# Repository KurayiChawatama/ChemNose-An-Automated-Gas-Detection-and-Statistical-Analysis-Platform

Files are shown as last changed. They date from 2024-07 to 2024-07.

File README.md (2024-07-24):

# ChemNose:An Automated Gas Detection and Statistical Analysis Platform

<div style="text-align: center;">
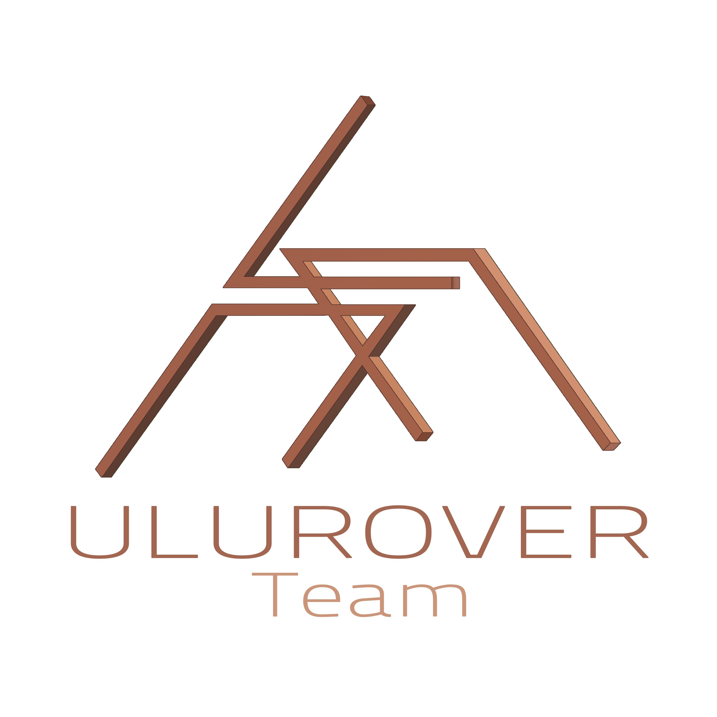
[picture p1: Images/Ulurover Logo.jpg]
ULUROVER Logo ULUROVER LOGO
    
</div>

## Table of Contents
- [Overview](#overview)
- [Materials And Methods](#materials-and-methods)
  - [The Weather Station Module](#the-weather-station-module)
    - [The Weather Station Module Carrying Case](#the-weather-station-module-carrying-case)
  - [The Gas Measurement Chamber For The Gas Detection Modules](#the-gas-measurement-chamber-for-the-gas-detection-modules)
  - [The Soil Moisture Module](#the-soil-moisture-module)
- [Data Analysis Pipeline](#data-analysis-pipeline)
  - [Weather Station Data Analysis](#weather-station-data-analysis)
  - [Gas Detection Data Analysis](#gas-detection-data-analysis)
  - [Soil Moisture Data Analysis](#soil-moisture-data-analysis)
- [Future Directions For the Project](#future-directions-for-the-project)

## Overview
ChemNose is an arduino based gas detection and chemical reaction observation platform. It is designed to be a low cost, portable, and easy to use platform for detecting gases and observing chemical reactions. The platform is built around an Arduino Uno and uses a variety of sensors to detect gases and observe chemical reactions. The platform is designed to be modular and expandable, allowing users to add additional sensors and modules as needed.

It was primarily designed for and used in simulated Mars and Moon exploration science missions for the Anatolian Rover Challenge 2024 by Uludağ University Rover Team (ULUROVER).
Their science team, under my leadership had a hypothesis investigating the habitability of Mars and Moon for Methanogenic Microorganisms. With this in mind, I designed the platform and data analysis pipeline to fit this task.

## Materials And Methods

The platform was built to mainly investigate the habitability of Mars for Methanogenic Microorganisms alongside other chemical assays that are beyond the scope of this document. The main simplified assumption of how a methanogenic microorganisms produce methane is outlined in the diagram below:

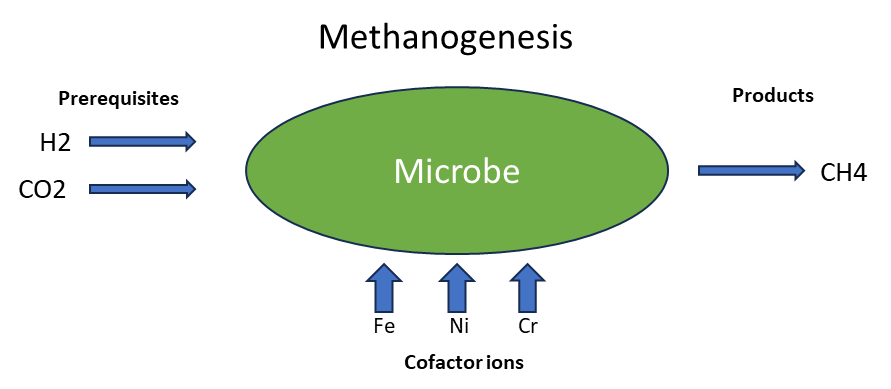
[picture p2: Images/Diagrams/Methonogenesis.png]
Methanogenesis Process Methanogenesis Diagram


The presence of and changes in the concentrations in ppm of the gases CO2, CH4 and H2 were measured using the MQ-135, MQ-4 and MQ-8 gas sensors respectively. The test for the presence of the other ions necessary for cofactors was done using ion specific chemicals assays.  

The general form of the platform 's pipeline is shown in the diagram below:

Pipeline Diagram Platform Pipeline Diagram

The platform consists of 4 modules:
- The Weather Station Module
- The Gas Detection Module with no SD card functionality
- The Gas Detection Module with SD card functionality
- The Soil Moisture Module

### The Weather Station Module

This is the main module that was designed to be run independent of a direct computer connection of the arduino uno. It's main purpose is to measure the temperature, humidity, CH4, CO2 and H2 concentration in the air during the Rover's missions. The data is stored in a SD card for later analysis as a timestamped CSV file in the %m/%d/%Y %H:%M:%S format. Readings are taken every 2 seconds to reduce error of the sensors for the output of a high quality dataset. 
The circuit diagram for the weather station module is shown below:

Weather Station Circuit Diagram

It consists fo the following sensors:
- DHT11 Temperature and Humidity Sensor
- MQ-135 Gas Sensor
- MQ-4 Gas Sensor
- MQ-8 Gas Sensor
- DS3231 RTC Module
- SD Card Module

**The components are configured as follows:**

DHT11 connections:
- D2

RTC connections:
- RST- D8
- DAT - D6
- CLK- D7
- **Note** RTC uses 3.3V not 5V

SD connections:
- CS- D4
- SCK- D13
- MOSI- D11
- MISO- D12

MQ-135: A0
MQ-4: A3
MQ-8: A1

#### The Weather Station Module Carrying Case

A 3D printable carrying case for the module was designed for easy mounting on the rover. It is a modular 3 piece design that can be easily assembled and disassembled. The design files for the carrying case can be found in the [`Weatherbox 3D Printable`](Weatherbox 3D Printable) folder.The overall schematics for the carrying case is shown below:

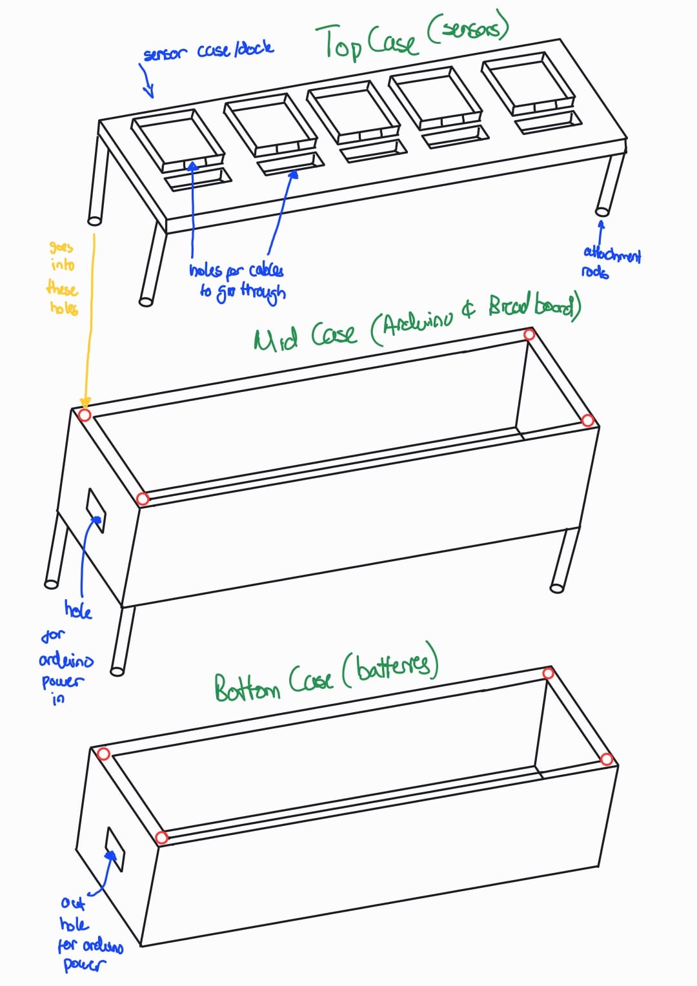
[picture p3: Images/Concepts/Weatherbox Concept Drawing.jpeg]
Weather Station Case Schematics


Placement of the circuit components in the case is shown below:

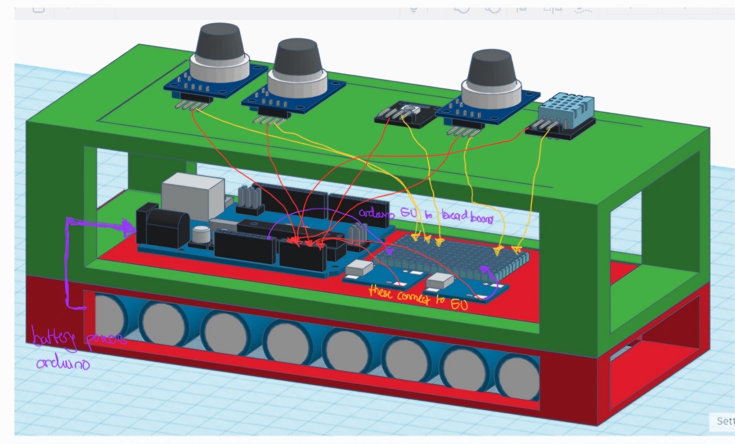
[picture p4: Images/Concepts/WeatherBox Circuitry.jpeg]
Weather Box Circuitry Placement


_(note, batteries are to be placed in two 4 AA battery holders that go into the bottom section of the case not side by side as the diagram depicts)_

The sensors will sit int the designated slots in the top of the case similar to the image shown below:

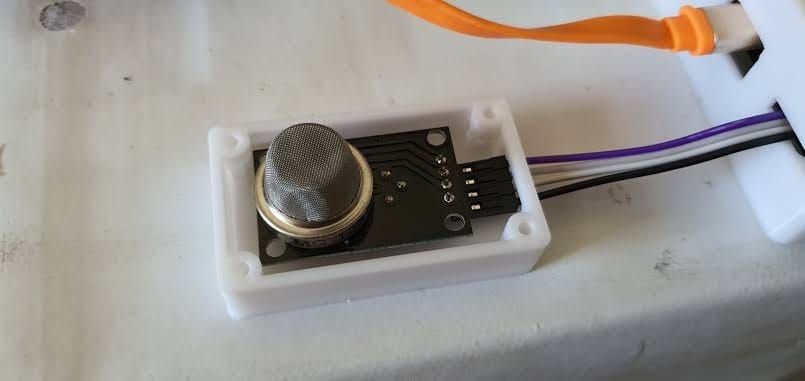
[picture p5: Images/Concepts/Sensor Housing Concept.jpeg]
Weather Box Sensor Placement


### The Gas Measurement Chamber For The Gas Detection Modules

The Circuit Diagram for the Gas Detection Modules are shown below:

<div style="display: flex; align-items: flex-start;">
    <div style="margin-right: 20px;">
        Gas Detection Circuit Diagram
        <p style="text-align: left;"><em>(without SD card functionality)</em></p>
    </div>
    <div>
        Gas Detection Circuit Diagram with SD Card Functionality
        <p style="text-align: left;"><em>(with SD card functionality)</em></p>
    </div>
</div>

It consists fo the following sensors:
- DHT11 Temperature and Humidity Sensor
- MQ-135 Gas Sensor
- MQ-4 Gas Sensor
- MQ-8 Gas Sensor
- SD Card Module(Optional)

**The components are configured as follows:**
SD connections:
- CS- D4
- SCK- D13
- MOSI- D11
- MISO- D12

MQ-135: A0
MQ-4: A3
MQ-8: A1

A novel 350ml closed gas chamber was designed and made using an airtight plastic container with holes to tightly fit the gas sensors. This allows for greater accuracy of the gs measurements. The chamber is setup is shown below:

<div style="display: flex; justify-content: space-around; align-items: center;">
    <div>
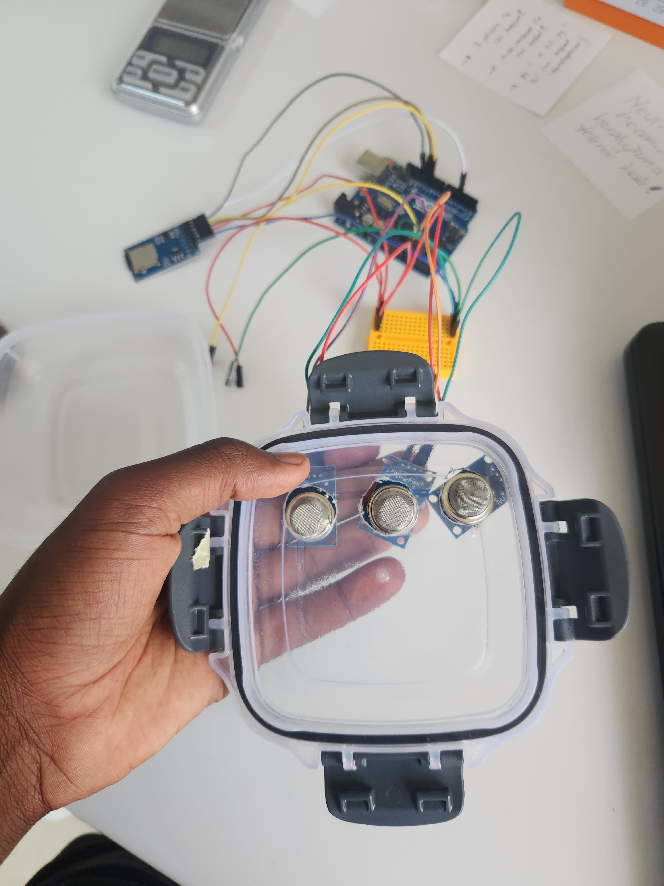
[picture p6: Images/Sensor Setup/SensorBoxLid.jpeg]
Sensor Box Lid
        
        <p style="text-align: center;"><em>Sensor Box Lid</em></p>
    </div>
    <div>
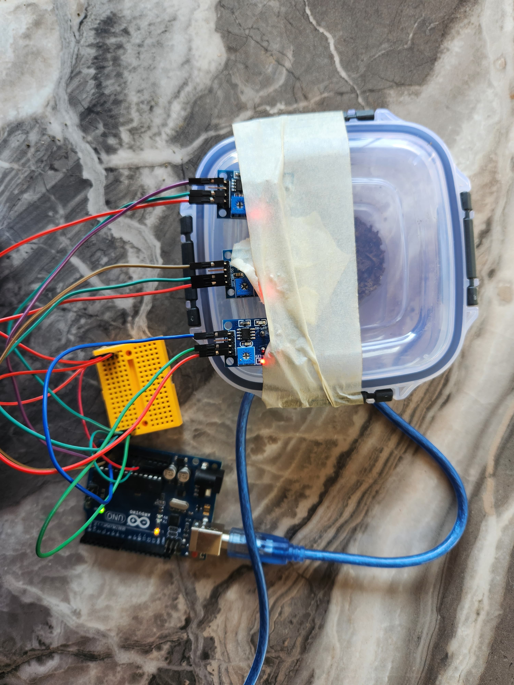
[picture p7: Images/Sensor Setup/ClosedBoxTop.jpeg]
Closed Box Top View
        
        <p style="text-align: center;"><em>Closed Box Top View</em></p>
    </div>
    <div>
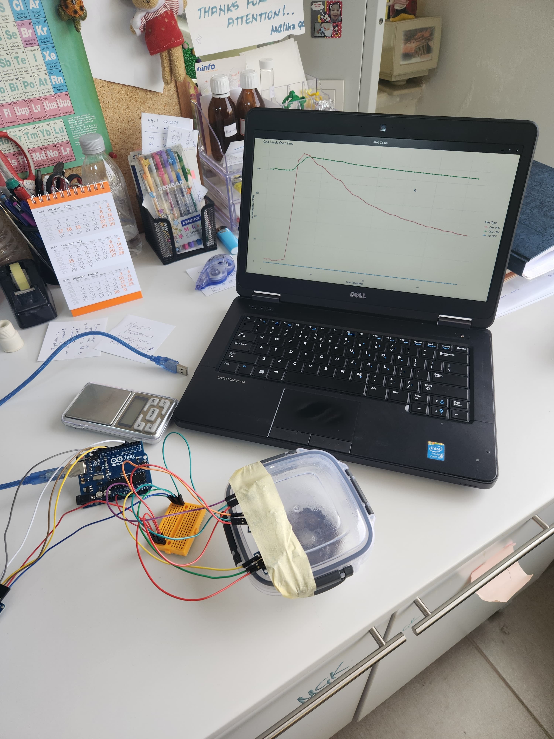
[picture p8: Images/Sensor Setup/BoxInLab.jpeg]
Box in Laboratory Setting
        
        <p style="text-align: center;"><em>Box in Laboratory Setting</em></p>
    </div>
    <div>
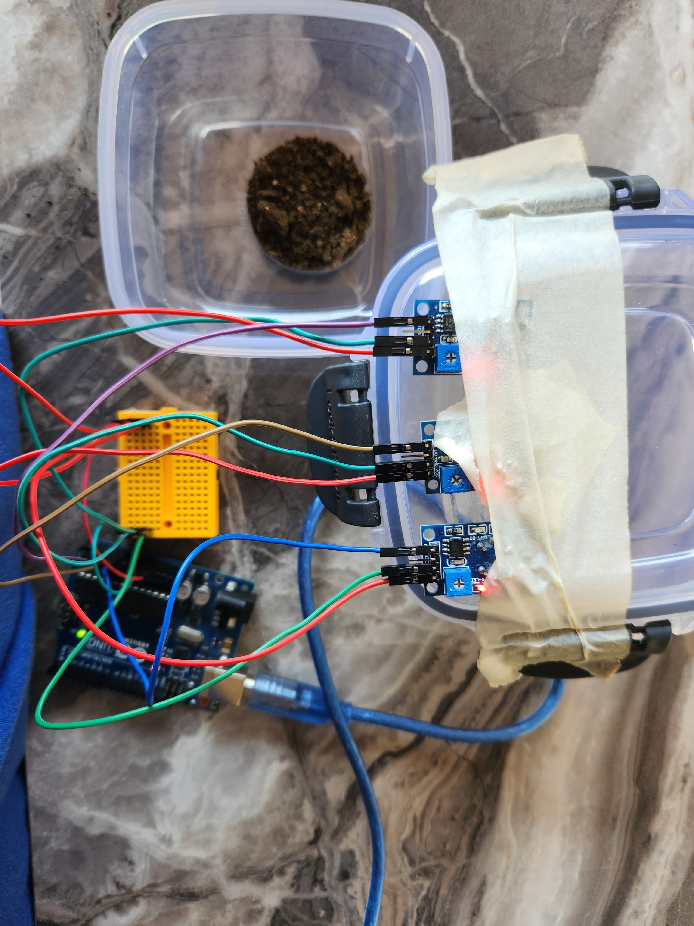
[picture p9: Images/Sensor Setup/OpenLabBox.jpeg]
Open Box in Laboratory
        
        <p style="text-align: center;"><em>Open Box in Laboratory</em></p>
    </div>
</div>

### The Soil Moisture Module

For measurement and classification of soil sample humidity in the lab setting, another module was designed using an arduino uno and a soil moisture sensor. **_This setup requires no specialized housing and does not return a CSV output for analysis_**. The circuit diagram for the soil moisture module is shown below: 

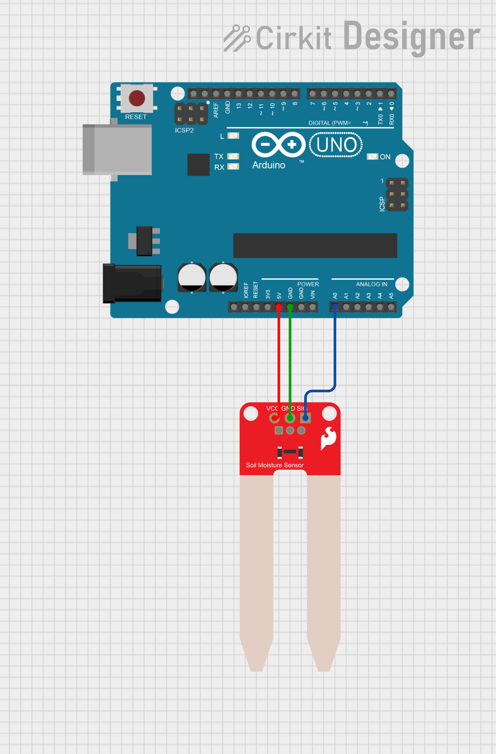
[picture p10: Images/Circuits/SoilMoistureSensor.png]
Weather Station Circuit Diagram


## Data Analysis Pipeline

### Weather Station Data Analysis

**Step 1: Data Collection**  
Set up the Weather Station Module and run the [Arduino_code/weatherStationNoUv/weatherStationNoUv.ino](Arduino_code/weatherStationNoUv/weatherStationNoUv.ino) Arduino sketch on the Arduino Uno. The data will be stored in a CSV file on the SD card in a name of your choosing.

**Step 2: Data Analysis**  
Retrieve the CSV file from the SD card and move it into the repository folder called [Sensor_data](Sensor_data). The data titled `DAY1.csv` and `DAY2.csv` is an example of the data that will be collected.  
Boxplot alongside textual summary statistics and Line plots of the metrics can be obtained by using the [R_code/day2Boxes.R](R_code/day2Boxes.R) and [R_code/day2Lines.R](R_code/day2Lines.R) scripts.

They generate plots like the ones shown below:

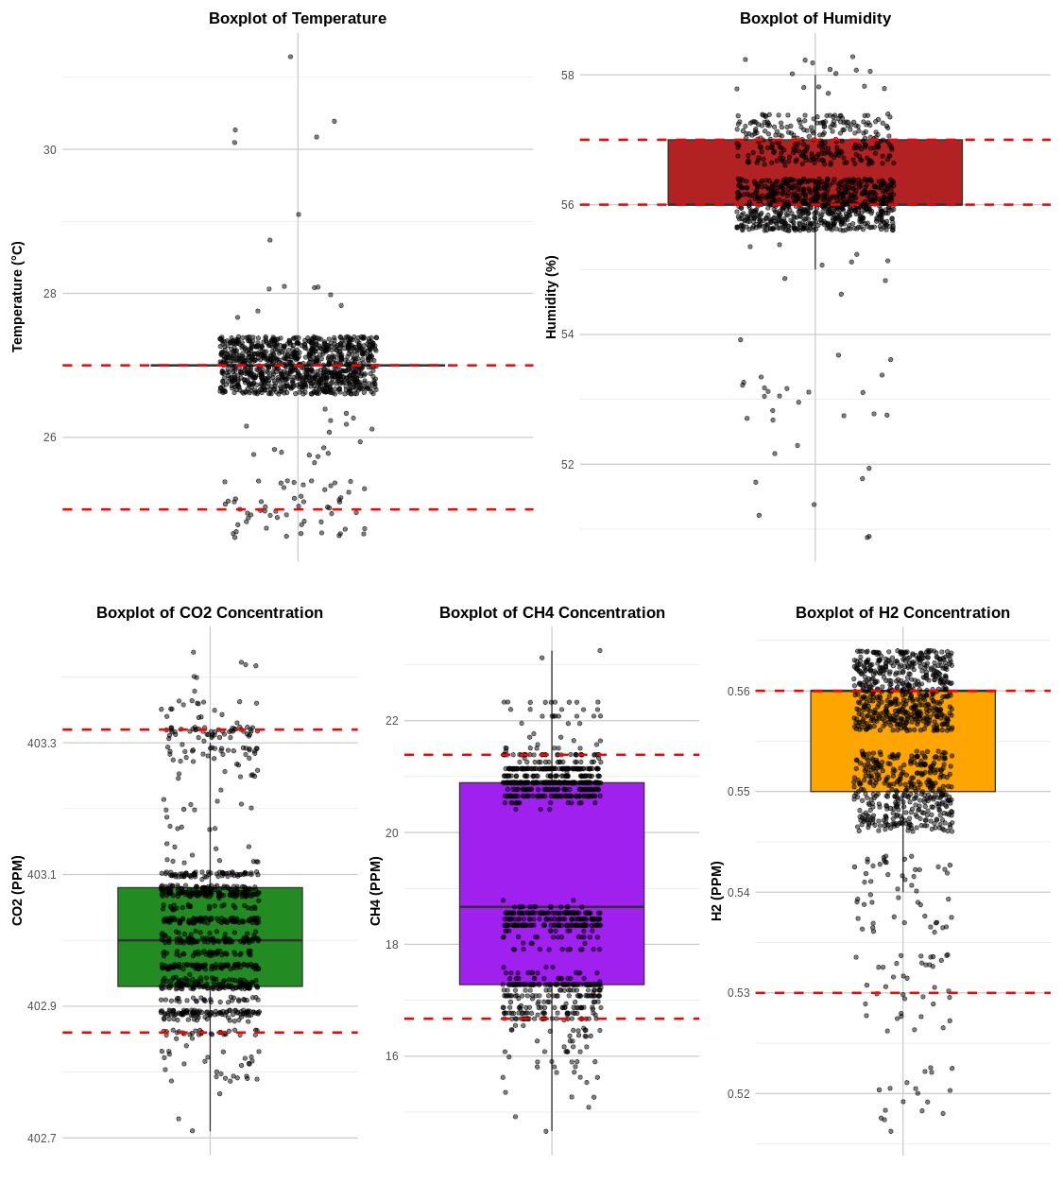
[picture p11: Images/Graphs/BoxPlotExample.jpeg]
Box Plot Example


_Box Plot Example_

Line Plot For Weather Example

_Day Line Plot Example_

### Gas Detection Data Analysis
The data analysis for gas can be done one of two ways; A mode purely for observation of gas levels in a soil sample or given reaction in the gas chamber and the second being a mode where data from multiple soil samples is compared together. 

Step 1: Data Collection
Set up the Gas Detection Module and run the [Arduino_code/MQsWSDCard/MQsWSDCard.ino](Arduino_code/MQsWSDCard/MQsWSDCard.ino) Arduino sketch on the Arduino Uno. The data will be stored in a CSV file on the SD card in a name of your choosing, or alternatively you can copy and paste the CSV output from the serial monitor and into a new CSV file.

Step 2: Data Analysis
- To simply observe the changes in gas levels in a soil sample or given reaction over time, you can use the [R_code/peroxideTestLine.R](R_code/peroxideTestLine.R) script. This script generates a line plot of the gas levels over time. To test the script, you can use the soilGasSample data or the Peroxide Reaction data in the [Sensor_data](Sensor_data) folder. This produces a plot like the one shown below:

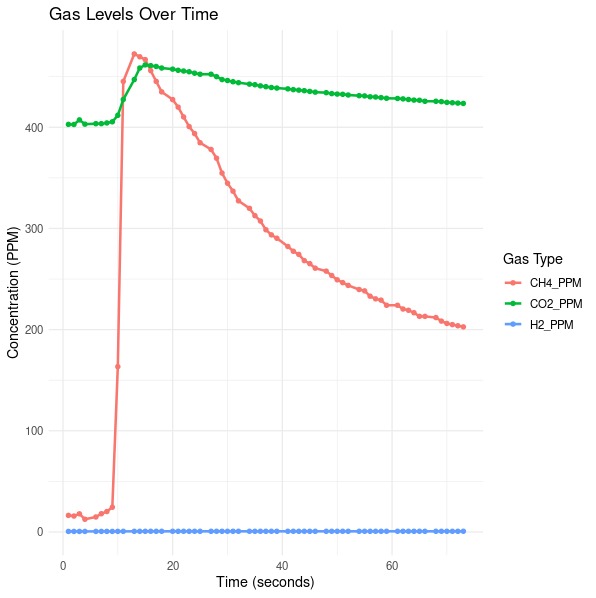
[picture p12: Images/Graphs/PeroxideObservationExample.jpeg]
Soil Gas Sample Line Plot


_Gas Change Over Time Line Plot. When Observing reactions sharper peaks indicate more vigorous reactions_

- To compare the changes in gas levels in multiple soil samples as well as an empty chamber, you can use the [R_code/barAllSoilComparison.R](R_code/barAllSoilComparison.R) and the [R_code/lineAllSoilComparison.R](R_code/lineAllSoilComparison.R) script. These scripts generate a patched graphic of line plots of gas change over time and bar plots of mean changes per gas side by side respectively. To test the script, you can use the soilGasSample data in the [Sensor_data](Sensor_data) folder. This produces plots like the ones shown below:

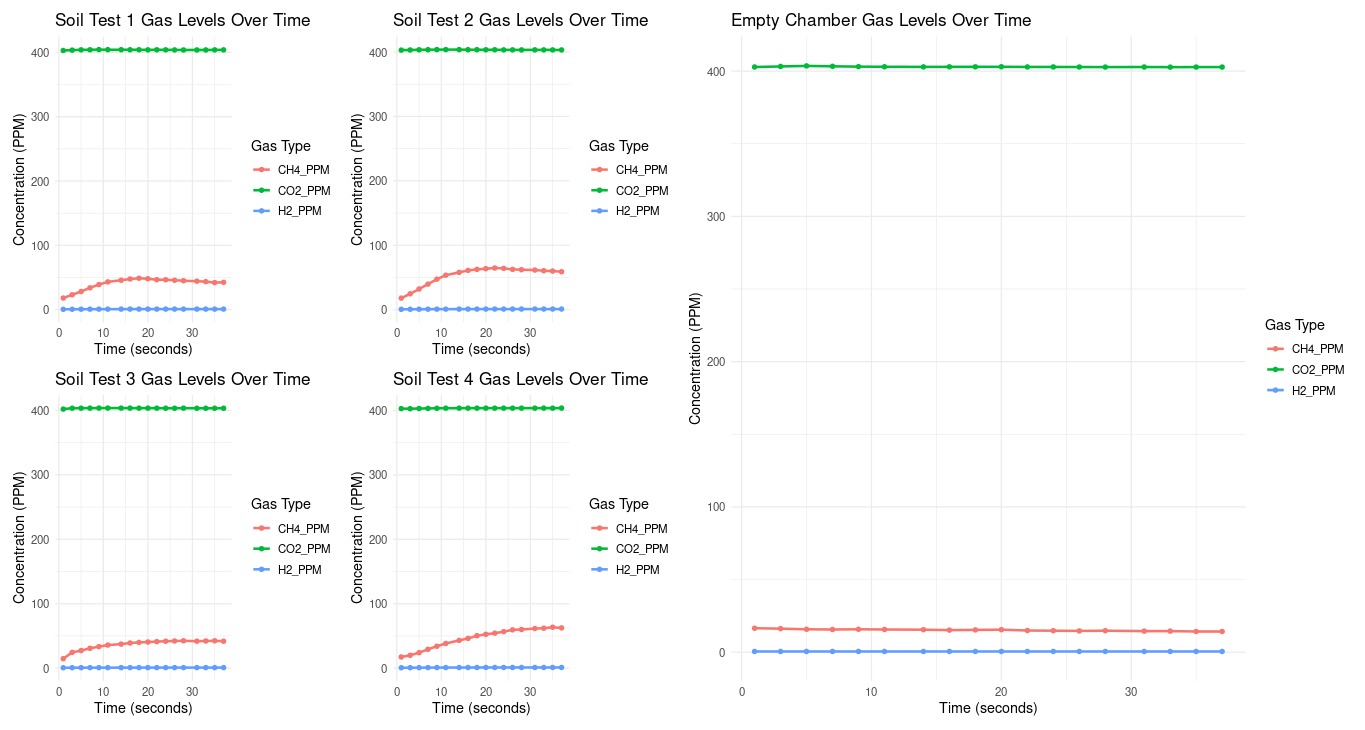
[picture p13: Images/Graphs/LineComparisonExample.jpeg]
All Soil Line Plot


_Multiple Sample Gas Change Over Time Comparison Line Plot_

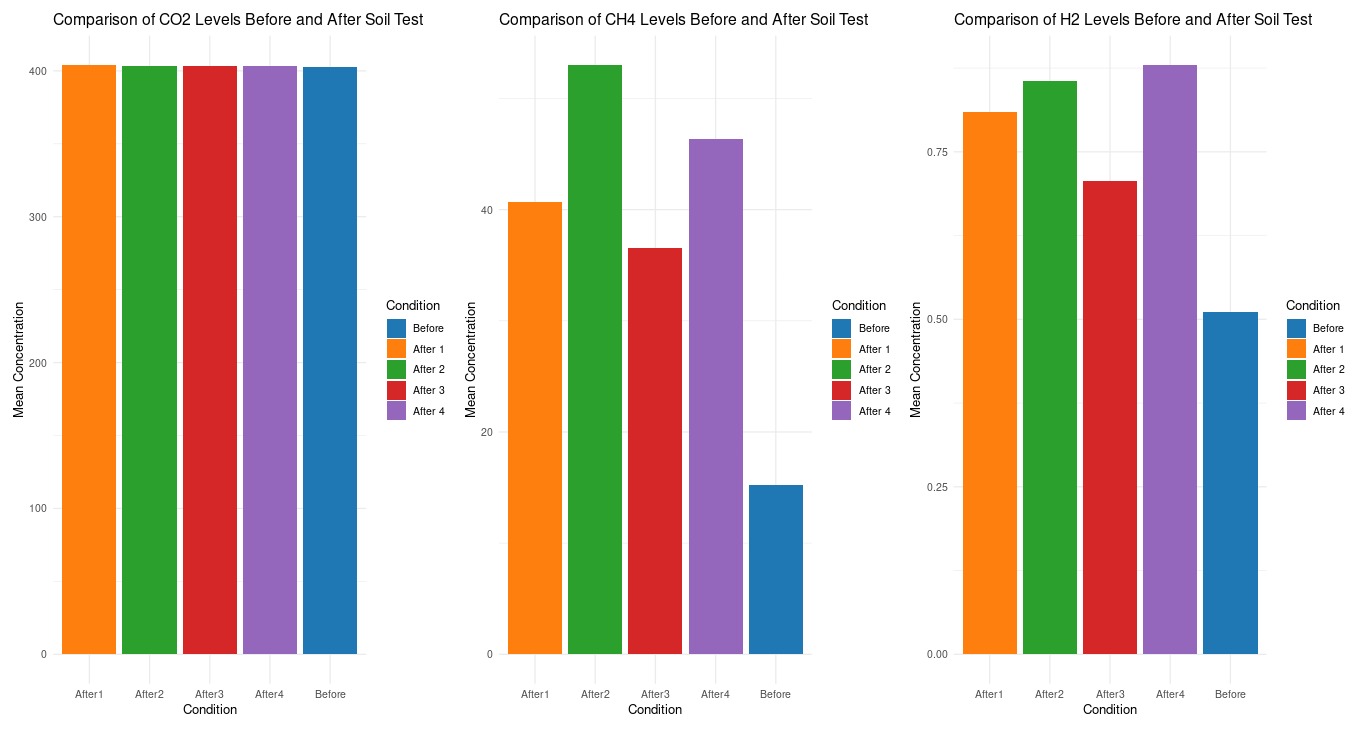
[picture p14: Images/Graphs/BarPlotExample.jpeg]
All Soil Bar Plot


_Multiple Sample Means Comparison Bar Plot_

- The [R_code/WilcoxonSigned-RankTest.R](R_code/WilcoxonSigned-RankTest.R) script can be used to perform a Wilcoxon Signed Rank Test on the data to determine if there is a significant difference in the gas levels between the soil samples and an empty gas chamber such that a conclusion can be made that the soil is the source of the gas. This script generates a textual output of the test results. To test the script, you can use the soilGasSample data in the [Sensor_data](Sensor_data) folder. The test follows the hypotheses:

```
(H₀): μ CH4 before = μ CH4 after |  (H₀): μ CO2 before = μ CO2 after | (H₀): μ H2 before = μ H2 after

(H₁): μ CH4 before < μ CH4 after | (H₁): μ CO2 before < μ CO2 after | (H₁): μ H2 before > μ H2 after
```

### Soil Moisture Data Analysis
This is quite straightforward and the data can be read an interpreted all by using the serial monitor output. 

## Additional Notes
- Make sure to set the load resistance value in Arduino/libraries/MQUnifiedsensor/MQUnifiedsensor.h to the correct value for the MQ sensors you are using. The default value is 10kΩ, the value on most modules is 1kΩ.
- The Project was largely inspired by Pineda, D. M., & Pérez, J. C. (2017). SENose: An under U$50 electronic nose for the monitoring of soil gas emissions. Computers and Electronics in Agriculture, 133, 15-21. https://doi.org/10.1016/j.compag.2016.12.004
- The Project was designed for efficient significance testing with small datasets.
- The Project is largely limited to use in a theoretical setting where sensors with a high margin of error are used. The data analysis pipeline is also not designed to fully account for this with appropriate normalization and scaling techniques.

## Future Directions For the Project
- Add a VEML6070 UV Sensor to the Weather Station to measure UV Index.
- Add a BME280 Sensor to the Weather Station for more accurate temperature and humidity readings as well as barometric pressure readings.
- Automate the data analysis process with a bash script.
- Add a CSV reading function to the arduino sketch to transfer data to the computer.

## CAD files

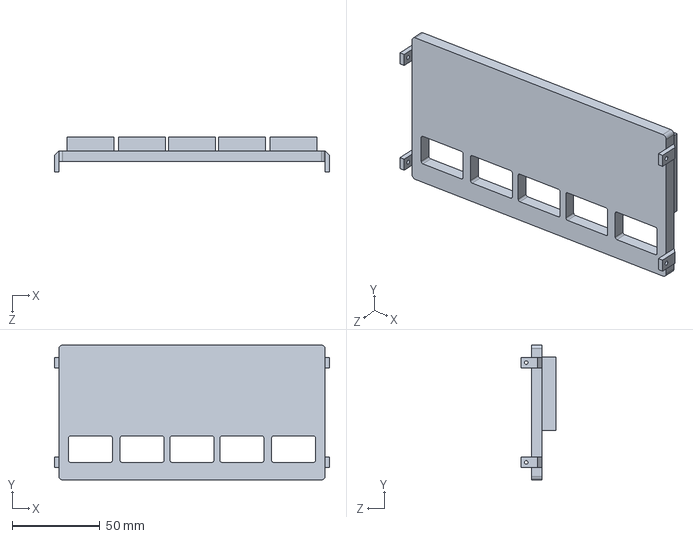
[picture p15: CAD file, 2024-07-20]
Weatherbox 3D Printable/top box3.SLDPRT
157.0 x 77.0 x 20.0 mm

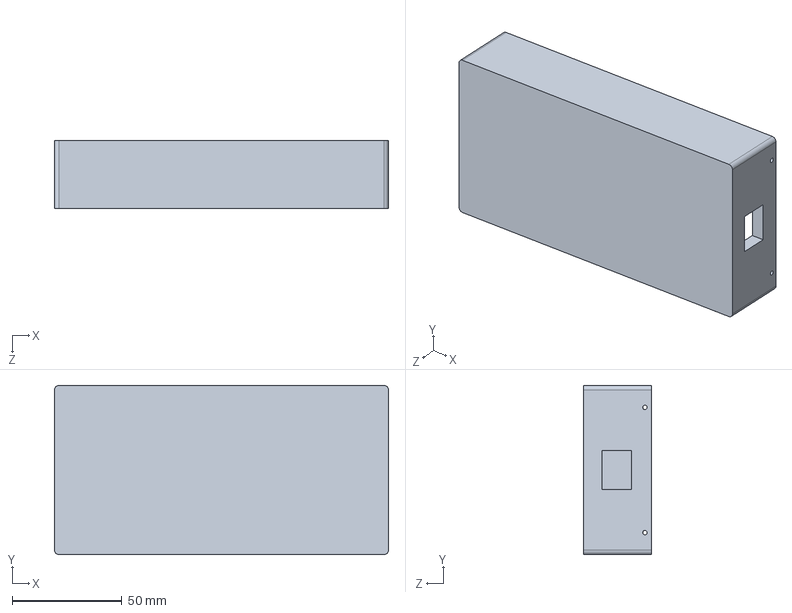
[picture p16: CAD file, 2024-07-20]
Weatherbox 3D Printable/bottom box2.SLDPRT
152.0 x 77.0 x 31.0 mm

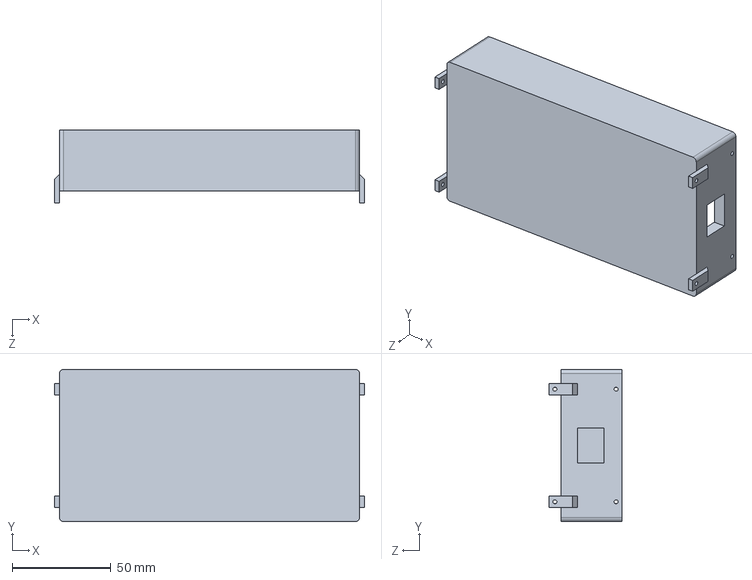
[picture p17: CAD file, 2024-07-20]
Weatherbox 3D Printable/mid box3.SLDPRT
157.0 x 77.0 x 37.0 mm

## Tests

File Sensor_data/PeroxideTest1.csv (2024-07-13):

Seconds | CO2_PPM | CH4_PPM | H2_PPM
1 | 402.85 | 16.39 | 0.53
2 | 402.75 | 15.72 | 0.53
3 | 407.30 | 17.92 | 0.53
4 | 403.06 | 12.55 | 0.53
6 | 403.54 | 14.80 | 0.53
7 | 403.58 | 18.03 | 0.55
8 | 404.26 | 20.17 | 0.55
9 | 405.41 | 24.43 | 0.55
10 | 411.81 | 163.37 | 0.59
11 | 427.44 | 445.33 | 0.62
13 | 447.15 | 472.46 | 0.63
14 | 458.56 | 469.66 | 0.64
15 | 461.67 | 466.89 | 0.65
16 | 460.88 | 455.97 | 0.65
17 | 460.10 | 445.33 | 0.65
18 | 458.56 | 434.97 | 0.65
20 | 457.44 | 427.37 | 0.65
21 | 456.33 | 419.91 | 0.65
22 | 455.60 | 410.19 | 0.65
23 | 454.88 | 400.72 | 0.65
24 | 453.46 | 393.77 | 0.65
25 | 452.42 | 384.71 | 0.65
27 | 452.42 | 378.06 | 0.65
28 | 450.05 | 369.40 | 0.65
29 | 447.15 | 354.74 | 0.65
30 | 446.22 | 344.66 | 0.65
31 | 445.00 | 336.82 | 0.65
32 | 444.10 | 327.29 | 0.65
34 | 442.63 | 319.88 | 0.65
35 | 442.06 | 312.64 | 0.65
36 | 440.93 | 307.33 | 0.65
37 | 440.11 | 298.70 | 0.65
38 | 439.29 | 293.64 | 0.65
39 | 438.76 | 290.32 | 0.65
41 | 437.97 | 282.20 | 0.65
42 | 437.19 | 277.44 | 0.65
43 | 436.68 | 274.32 | 0.65
44 | 436.18 | 268.18 | 0.65
45 | 435.43 | 265.17 | 0.65
46 | 434.70 | 260.72 | 0.65
48 | 434.22 | 257.80 | 0.65
49 | 433.27 | 253.48 | 0.65
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

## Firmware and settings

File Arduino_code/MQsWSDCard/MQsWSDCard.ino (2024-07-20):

/**
 * @file MQsWSDCard.ino
 * @brief Gas Level Monitoring and Data Logging
 *
 * This sketch is designed for the ChemNose project to automate gas detection and analysis by collecting readings
 * from MQ-135, MQ-4, and MQ-8 sensors and saving the data to an SD card. It focuses on monitoring CO2, CH4, and H2
 * gas levels for environmental monitoring and analysis.
 *
 * @author Kurayi Chawatama
 * @date 2024-07-20
 *
 * @note This code is integral to the ChemNose project's objective of providing a comprehensive environmental
 * monitoring solution. It leverages the Arduino platform and specific gas sensors to gather and log data,
 * facilitating further analysis of gas concentrations in various environments.
 * - The MQ unified sensor library head file was edited to a load resistor of 1k ohms
 *
 * @see For detailed information on the MQUnifiedsensor library and sensor calibration, consult the official
 * documentation and GitHub repository of the MQUnifiedsensor project.
 */

#include <MQUnifiedsensor.h>
#include <SPI.h>
#include <SD.h>

// Sensor Definitions
// MQ-135 for detecting a wide range of gases, including CO2
#define PlacaMQ135 "Arduino UNO"
#define PinMQ135 A0
#define TypeMQ135 "MQ-135"
#define VoltageResolution 5
#define ADCBitResolution 10
#define RatioMQ135CleanAir 3.6

// MQ-4 for detecting methane (CH4) levels
#define BoardMQ4 "Arduino UNO"
#define PinMQ4 A3 // Analog input A3 of your Arduino
#define TypeMQ4 "MQ-4"
#define RatioMQ4CleanAir 4.4

// MQ-8 for detecting hydrogen (H2) gas
#define BoardMQ8 "Arduino UNO"
#define PinMQ8 A1 // Analog input A1 of your Arduino
#define TypeMQ8 "MQ-8"
#define RatioMQ8CleanAir 70
#define AdjustFactorMQ8 100.0 // Adjust factor for MQ-8 output

MQUnifiedsensor MQ135(PlacaMQ135, VoltageResolution, ADCBitResolution, PinMQ135, TypeMQ135);
MQUnifiedsensor MQ4(BoardMQ4, VoltageResolution, ADCBitResolution, PinMQ4, TypeMQ4);
MQUnifiedsensor MQ8(BoardMQ8, VoltageResolution, ADCBitResolution, PinMQ8, TypeMQ8);

#define CHIP_SELECT 4 // Define SD card chip select pin

const char *filename = "levels.csv"; // Use a shorter filename for compatibility

unsigned long previousMillis = 0; // Store the last time measurement was made
int seconds = 0; // Initialize seconds counter

void setup() {
  // Serial and SD Card Initialization
  // Initializes serial communication and the SD card module, creating a new CSV file if it doesn't exist.
  Serial.begin(9600);
  while (!Serial) {
    ; // Wait for serial port to connect
  }

  Serial.print("Initializing SD card...");
  if (!SD.begin(CHIP_SELECT)) {
    Serial.println("Card failed, or not present");
    while (1);
  }
  Serial.println("Card initialized.");

  if (!SD.exists(filename)) {
    File dataFile = SD.open(filename, FILE_WRITE);
    if (dataFile) {
      dataFile.println("Seconds,CO2_PPM,CH4_PPM,H2_PPM");
      dataFile.close();
      Serial.println("CSV header written.");
    } else {
      Serial.println("Error opening gas_levels.csv to write header");
    }
  } else {
    Serial.println("CSV file already exists.");
  }

  // Sensor Initialization
  // Configures each gas sensor with specific calibration and regression settings.
  MQ135.setRegressionMethod(1); // Using linear regression
  MQ135.setA(110.47); MQ135.setB(-2.862);
  MQ135.init();

  MQ4.setRegressionMethod(1); // Using linear regression
  MQ4.setA(1012.7); MQ4.setB(-2.786);
  MQ4.init();

  MQ8.setRegressionMethod(1); // Using linear regression
  MQ8.setA(976.97); MQ8.setB(-0.688);
  MQ8.init();
}

void loop() {
  // Main Loop
  // Collects readings from each sensor every second, formats the data, and saves it to the SD card.
  unsigned long currentMillis = millis();
  if (currentMillis - previousMillis >= 1000) {
    previousMillis = currentMillis;
    seconds++;

    // Reading Gas Levels
    MQ135.update();
    float CO2_PPM = MQ135.readSensor() + 400; // Adjust CO2 PPM to correct offset

    MQ4.update();
    float CH4_PPM = MQ4.readSensor();

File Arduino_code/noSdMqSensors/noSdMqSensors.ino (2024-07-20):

/**
 * @file noSdMqSensors.ino
 * @brief Gas Concentration Monitoring without SD Card Logging
 *
 * This sketch is designed for the ChemNose project to monitor gas concentrations from MQ-135, MQ-4, and MQ-8 sensors
 * and display the readings of CO2, CH4, and H2 gases on the serial monitor. It operates without the need for an SD card,
 * making it suitable for real-time monitoring or integration into larger systems where data logging is handled elsewhere.
 *
 * The readings are adjusted for offsets and displayed in parts per million (PPM), providing immediate insights into
 * the environmental conditions being monitored. This setup is optimized for quick deployment and testing, offering
 * a streamlined approach to gas detection with the ChemNose project's sensor array.
 *

 * @author Kurayi Chawatama
 * @date 2024-07-20
 *
 * @note This code is a simplified version of the ChemNose project's environmental monitoring suite, focusing on
 * gas concentration measurements without data logging capabilities. It demonstrates the flexibility of the project's
 * hardware and software design, allowing for various configurations based on specific research or operational needs.
 * - The MQ unified sensor library head file was edited to a load resistor of 1k ohms
 * @see For more information on the MQUnifiedsensor library and sensor calibration, consult the official documentation
 * and GitHub repository of the MQUnifiedsensor project.
 */

#include <MQUnifiedsensor.h>

// Sensor Definitions
// MQ-135 for CO2 detection
#define PlacaMQ135 "Arduino UNO"
#define PinMQ135 A0
#define TypeMQ135 "MQ-135"
#define VoltageResolution 5
#define ADCBitResolution 10
#define RatioMQ135CleanAir 3.6

// MQ-4 for CH4 (methane) detection
#define BoardMQ4 "Arduino UNO"
#define PinMQ4 A3 // Analog input A3 of your Arduino
#define TypeMQ4 "MQ-4"
#define RatioMQ4CleanAir 4.4

// MQ-8 for H2 (hydrogen) detection
#define BoardMQ8 "Arduino UNO"
#define PinMQ8 A1 // Analog input A1 of your Arduino
#define TypeMQ8 "MQ-8"
#define RatioMQ8CleanAir 70

// Sensor initialization
MQUnifiedsensor MQ135(PlacaMQ135, VoltageResolution, ADCBitResolution, PinMQ135, TypeMQ135);
MQUnifiedsensor MQ4(BoardMQ4, VoltageResolution, ADCBitResolution, PinMQ4, TypeMQ4);
MQUnifiedsensor MQ8(BoardMQ8, VoltageResolution, ADCBitResolution, PinMQ8, TypeMQ8);

void setup() {
  Serial.begin(9600);
  Serial.println("Seconds,CO2_PPM,CH4_PPM,H2_PPM");

  // Sensor setup and calibration
  // MQ-135 Setup
  MQ135.setRegressionMethod(1); // Set linear regression method for more accurate readings
  MQ135.setA(110.47); // Set 'A' parameter of the equation
  MQ135.setB(-2.862); // Set 'B' parameter of the equation
  MQ135.init(); // Initialize the sensor

  // Calibrate MQ-135 and calculate R0 value
  float calcR0MQ135 = 0;
  for (int i = 0; i < 10; i++) {
    MQ135.update(); // Update sensor value
    calcR0MQ135 += MQ135.calibrate(RatioMQ135CleanAir); // Calibrate with clean air ratio
  }
  MQ135.setR0(calcR0MQ135 / 10); // Set the calculated R0

  // Repeat setup and calibration for MQ-4 and MQ-8 sensors
  // MQ-4 Setup
  MQ4.setRegressionMethod(1);
  MQ4.setA(1012.7); MQ4.setB(-2.786);
  MQ4.init();

  float calcR0MQ4 = 0;
  for (int i = 0; i < 10; i++) {
    MQ4.update();
    calcR0MQ4 += MQ4.calibrate(RatioMQ4CleanAir);
  }
  MQ4.setR0(calcR0MQ4 / 10);

  // MQ-8 Setup
  MQ8.setRegressionMethod(1);
  MQ8.setA(976.97); MQ8.setB(-0.688);
  MQ8.init();

  float calcR0MQ8 = 0;
  for (int i = 0; i < 10; i++) {
    MQ8.update();
    calcR0MQ8 += MQ8.calibrate(RatioMQ8CleanAir);
  }
  MQ8.setR0(calcR0MQ8 / 10);
}

void loop() {

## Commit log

2024-07-04 Update and rename One_I_actually_Wrote.ino to LED_Fade.ino
2024-07-13 Added R files and sensor data via uploads
    [DAY2.CSV, Labstest1.csv, WEATHER.CSV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]
2024-07-13 Added Arduino files via upload
2024-07-13 Organized files
    [DAY2.CSV, Labstest1.csv, WEATHER.CSV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]
2024-07-13 More file organization
    [DAY1.CSV, DAY2.CSV, Labstest1.csv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]
2024-07-13 Corrected file names, changed hypthesis test to wilcox from T, deleted useless code
    [Labstest1.csv, SoilSample1.csv, WEATHER.CSV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]
2024-07-20 Added Images To The Readme Directory
    [bottom box2.SLDPRT, mid box3.SLDPRT, top box3.SLDPRT]
2024-07-20 Addded Documentation to Arduino Sketches
2024-07-24 Updated the readme to include more detailed descriptions of all the modules and circuits
